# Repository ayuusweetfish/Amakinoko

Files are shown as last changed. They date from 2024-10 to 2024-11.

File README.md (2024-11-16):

# 天气蘑菇 · アマキノコ · Amakinoko

一个蘑菇外形的彩灯装置，流动的颜色依天气变化。光效亦可通过 USB 连接电脑定制。

[**汇报展示与视频**](https://ayuusweetfish.github.io/Amakinoko/)  
[**Rev. 2 资料**](https://github.com/ayuusweetfish/Amakinoko/releases/tag/rev-2)

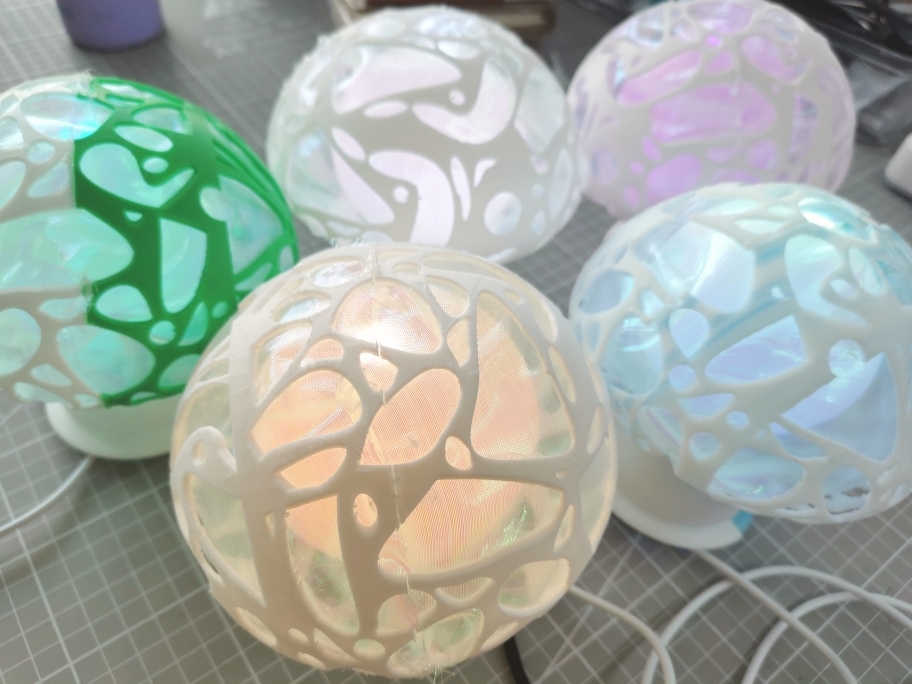
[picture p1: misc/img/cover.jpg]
封面图，蘑菇外形的色彩各异的灯


## 食谱

材料
- 3D 打印外壳元件
- 炫彩纱布（？）
- WS2812/WS2812B 灯带（5050 灯珠；每米 96 灯，取 24 灯）
- 2.54 mm 排针
- 2.54 mm 跳线（杜邦线），双端孔头
- 组装电路板（PCBA）
- 胶水，如 UHU 胶
- （可选）热熔胶
- （可选）镀银纱线

步骤
1. 将纱布用胶水粘贴在两片外壳上；
2. 将 3 pin 排针焊接在灯带首端；
3. 将灯带打结成球状，尽可能使每一个朝向都有小灯；
4. 将灯带上的排针插入杜邦线，连接至电路板；
5. 将灯带与杜邦线固定在内胆内侧（可用胶水或热熔胶），保持灯带悬空在中央位置；
6. （可选）若有镀银纱线，可将其随意粘贴在外壳内壁，另一端穿过电路板上的触摸传感孔，打结、粘贴固定；
7. 将外壳与内胆粘贴固定；
8. 连接 USB 电源即可。

注：3D 打印与 PCBA 的组装未列入。PCBA 组装可参考 KiCad 工程文件；完成后通过 DAP 调试器向 STM32 微控制器写入固件，再通过蘑菇配置工具写入灯光程序。

## 定制灯光

通过 USB 数据线将装置连接至计算机，运行配置工具软件（发布页面提供 Windows 与 macOS 版本下载）。连接后即可看到实时读数、灯光颜色与光效程序。

光效程序运行在 [Mumu 虚拟机](./misc/mumu)中，目前以 Mumu 汇编语言撰写。Mumu 是一个结构简单的虚拟计算模型，其上的程序能访问 2 KiB 的内存空间。

## 目录组织
- **hw/**: 印刷电路板工程文件
- **fw/**: STM32 微控制器固件源程序
- **mech/**: 外壳 3D 模型
- **cfg/**: PC 配置工具软件源程序

部分文件可以通过以下软件打开（版本号作为参考）：
- 外壳：3D One
- 电路板：KiCad (7.0.10)
- 固件：Arm GNU Toolchain (GCC 10.3.1), STM32CubeG0 (1.5.0), PlatformIO (6.1.16)

## 许可

本仓库内的所有内容按照 CERN-OHL-S（CERN 开放硬件许可证第 2 版，强互惠条件）分发。完整原文参见 **COPYING.txt** 或[在线访问](https://ohwr.org/cern_ohl_s_v2.txt)。

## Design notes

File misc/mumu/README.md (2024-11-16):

# 微木 · Mumu

Mumu 是一个结构简单的虚拟机（抽象的计算模型），可以在资源有限的平台上创造相对灵活的计算环境。

## Mumu 计算模型

- Harvard 架构，随机存储（RAM）与只读存储（ROM）分离，每个存储单元均为 32 位
- 程序从 ROM 地址 0 处开始执行，每条指令占一个存储单元
- 256 个“通用寄存器” %0 \~ %255，直接映射到随机存储单元 0 \~ 255
- “堆栈指针寄存器” SP 为随机存储单元 M-1，其中 M 为随机存储单元总数

## Mumu 汇编语言

单个大写字母均表示寄存器（均指通用寄存器，不包括 SP，下同）。

参考：[Fibonacci 数列](./fib.mumu)、[天气蘑菇彩虹光效](./lights/3.mumu)。

### 算术
```
<op>  <A> <B> <C>     # A := B (op) C
<op>  <A> <B> <Imm8>  # A := B (op) Imm8
<op>  <A> <Imm16>     # A := A (op) Imm16
<op>  <A> <Imm16>     # A := A (op) (Imm16 << 16)
```
其中 `<op>` 为 `mov`/`add`/`sub`/`mul`/`and`/`or`/`xor`/`bic`/`lsr`/`asr`/`lsl` 之一。

### 访存
```
ld    <A> <B> <C>  # A := RAM[B + C]
st    <A> <B> <C>  # RAM[B + C] := A
ldc   <A> <B> <C>  # A := ROM[B + C]
ldcr  <A> <B> <C>  # A := ROM[PC + B + C]
```
另外，访存指令中所有的 `<C>` 也可以为 8 位立即值。

### 控制流
```
br<cond>  <A> <B> <Imm8>      # PC := PC + Imm8
br<cond>  <A> <Imm8B> <Imm8C> # PC := PC + Imm8C
br<cond>  <A> <B> <C>         # PC := PC + C
ba<cond>  <A> <B> <C>         # PC := C
baf       <Imm24>             # PC := Imm24
```
其中 `<cond>` 为 `al`/`eq`/`ne`/`gt`/`lt`/`ge`/`le`/`sgt`/`slt`/`sge`/`sle` 之一。

### 堆栈与子过程
```
push  <A> <Imm8>    # SP := SP - Imm8; RAM[SP..=SP+Imm8-1] = A..=A+Imm8-1
pop   <A> <Imm8>    # A..=A+Imm8-1 = RAM[SP..=SP+Imm8-1]; SP := SP + Imm8
call  <Imm24>       # push PC+1; baf Imm24
ret                 # pop PC
```

### 系统呼叫
```
sc  <Imm24>
```

## Mulin

希望以后能提供更加易于上手的语言。暂时还没有开始。

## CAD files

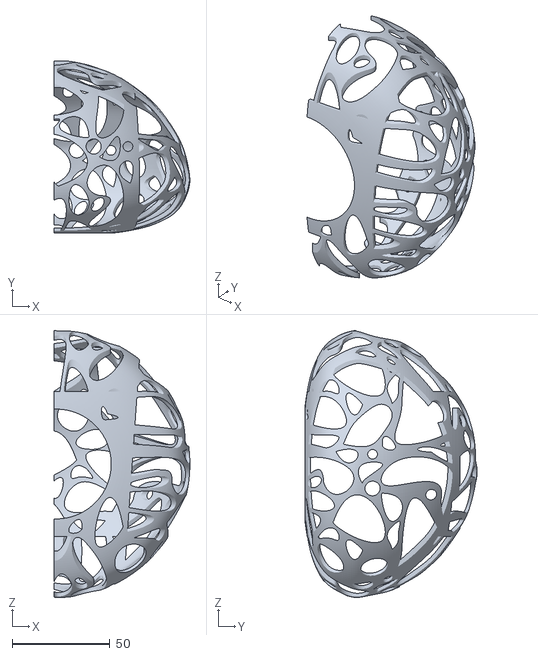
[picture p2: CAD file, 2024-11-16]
mech/rev2/蘑菇2.0（头2）.stl
69.5 x 88.3 x 136.7

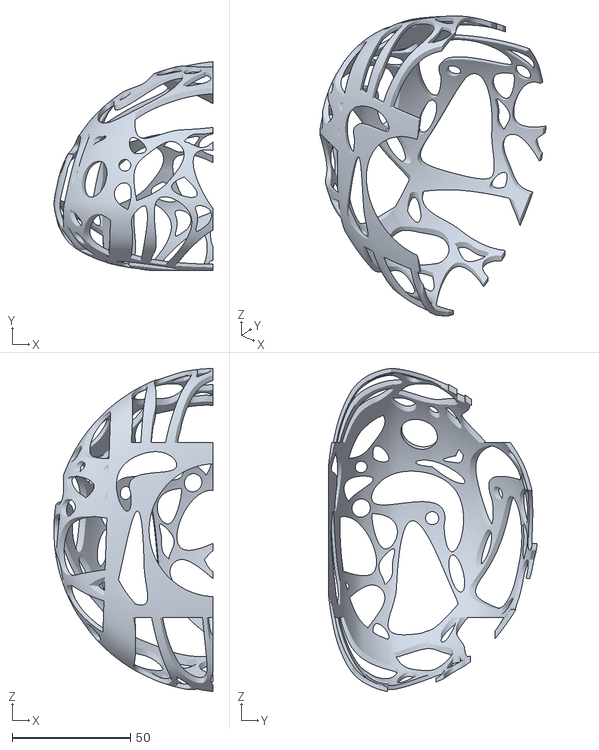
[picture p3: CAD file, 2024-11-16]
mech/rev2/蘑菇2.0(头1).stl
67.1 x 88.1 x 136.5

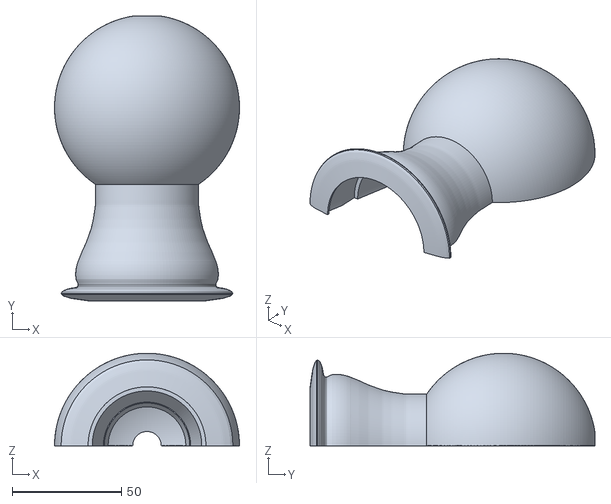
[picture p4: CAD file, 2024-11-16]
mech/rev2/蘑菇2.0（身）.stl
84.8 x 130.5 x 42.4

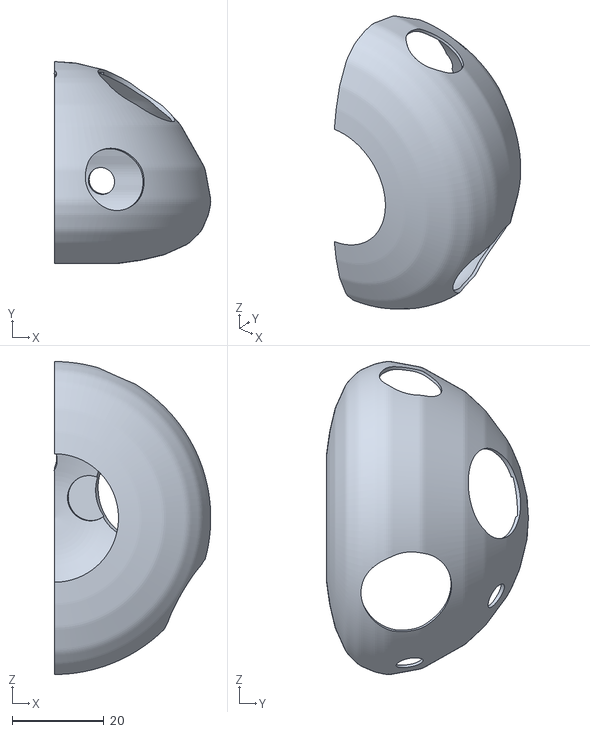
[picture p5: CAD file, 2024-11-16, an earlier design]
mech/rev1/小蘑菇头2.stl
34.2 x 44.1 x 68.4

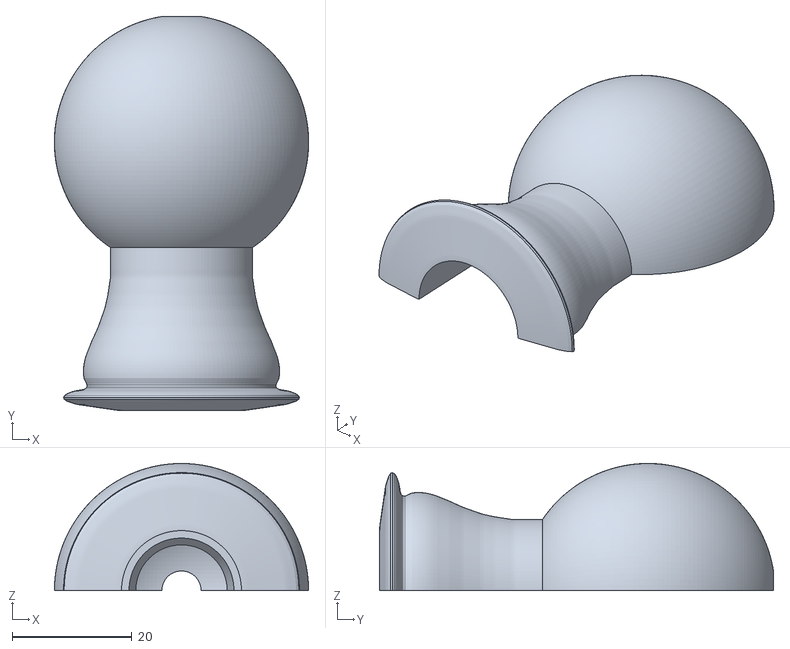
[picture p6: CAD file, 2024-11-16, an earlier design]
mech/rev1/小蘑菇柄1.stl
42.4 x 65.7 x 21.2

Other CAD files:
mech/rev1/小蘑菇头1.stl
mech/rev1/小蘑菇柄2.stl

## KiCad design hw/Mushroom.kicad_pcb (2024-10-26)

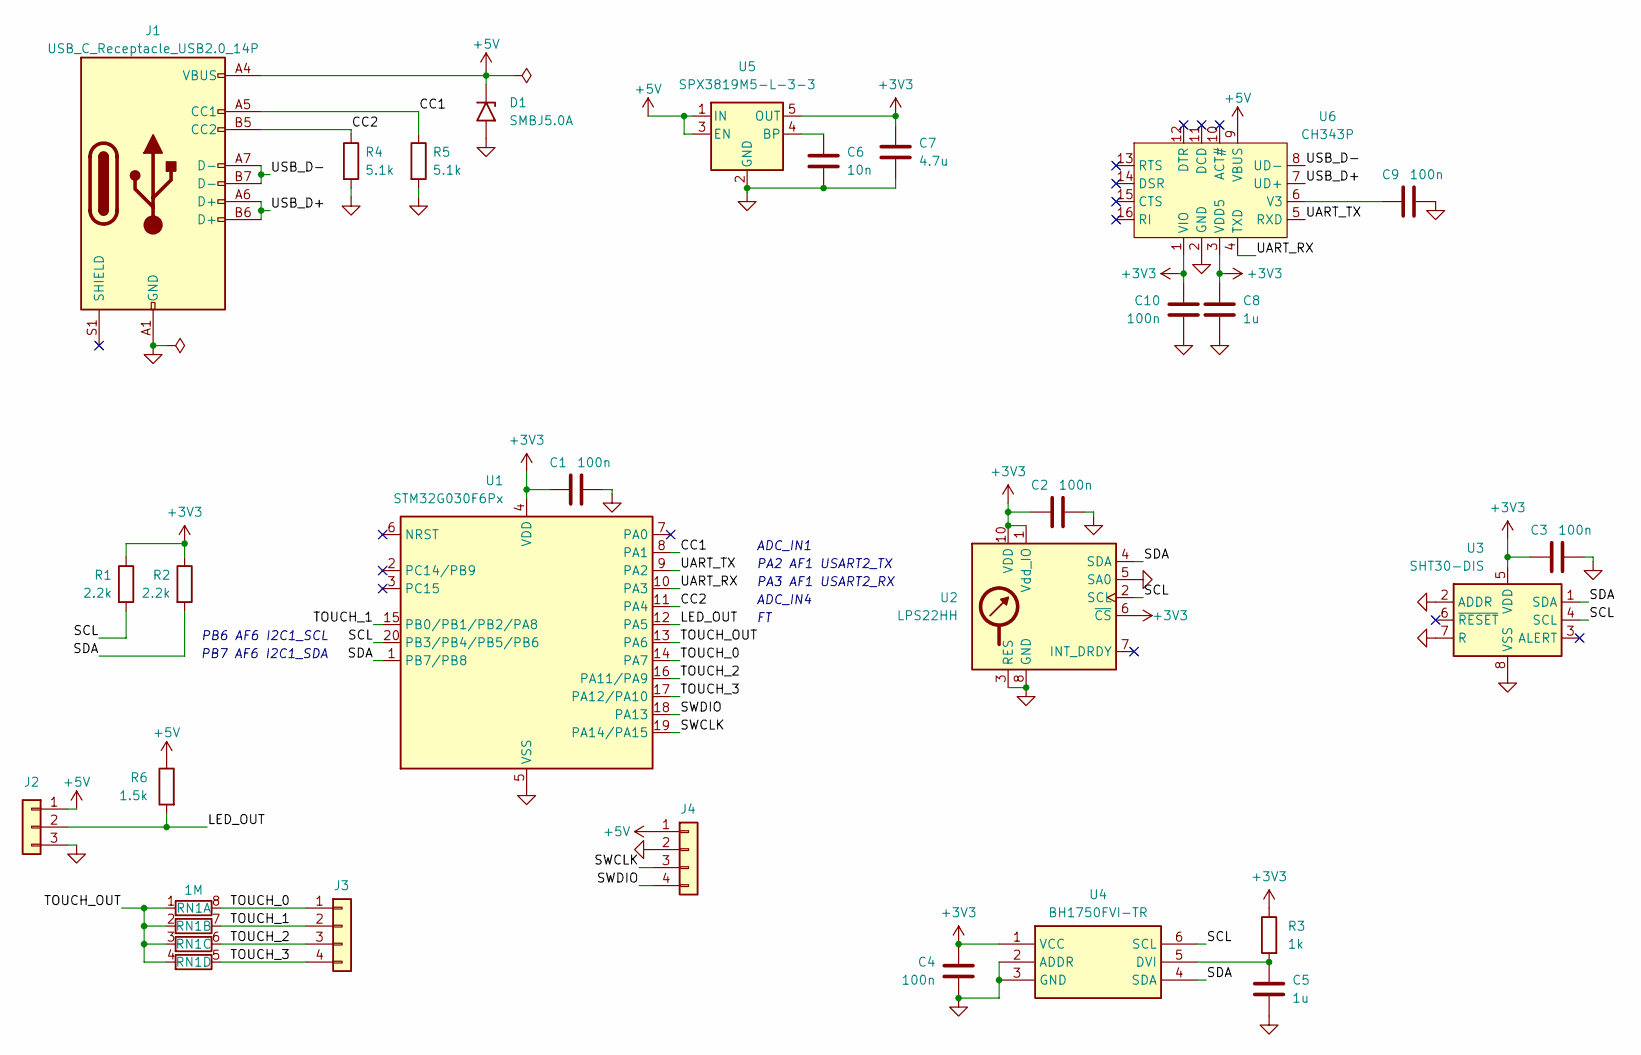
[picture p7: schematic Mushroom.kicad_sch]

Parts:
C1, C2, C3, C4, C9, C10: 100n; C_0402_1005Metric
C5, C8: 1u; C_0402_1005Metric
C6: 10n; C_0402_1005Metric
C7: 4.7u; C_0402_1005Metric
D1: SMBJ5.0A; D_SMB
J1: USB_C_Receptacle_USB2.0_14P; USB_C_Receptacle_HRO_TYPE-C-31-M-12
J2: Conn_01x03; PinHeader_1x03_P2.54mm_Vertical
J3: Conn_01x04; Arc_Pins_04
J4: Conn_01x04; TestPoints_1x04_P2.0
R1, R2: 2.2k; R_0402_1005Metric
R3: 1k; R_0402_1005Metric
R4, R5: 5.1k; R_0402_1005Metric
R6: 1.5k; R_0402_1005Metric
RN1: 1M; R_Array_Convex_4x0402
U1: STM32G030F6Px; TSSOP-20_4.4x6.5mm_P0.65mm
U2: LPS22HH; ST_HLGA-10_2x2mm_P0.5mm_LayoutBorder3x2y
U3: SHT30-DIS; Sensirion_DFN-8-1EP_2.5x2.5mm_P0.5mm_EP1.1x1.7mm
U4: BH1750FVI-TR; WSOF6; Manufacturer_Part_Number BH1750FVI-TR; Mouser Part Number 755-BH1750FVI-TR
U5: SPX3819M5-L-3-3; SOT-23-5
U6: CH343P; QFN-16-1EP_3x3mm_P0.5mm_EP1.9x1.9mm

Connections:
+3V3: C1.1, C2.1, C3.1, C4.1, C7.1, C8.1, C10.1, R1.1, R2.1, R3.1, U1.4 (VDD), U2.1 (Vdd_IO), U2.6 (~CS), U2.10 (VDD), U3.5 (VDD), U4.1 (VCC), U5.5 (OUT), U6.1 (VIO), U6.3 (VDD5)
+5V: D1.1 (A1), J1.A4 (VBUS), J1.A9 (VBUS), J1.B4 (VBUS), J1.B9 (VBUS), J2.1, J4.1, R6.1, U5.1 (IN), U5.3 (EN), U6.9 (VBUS)
/CC1: J1.A5 (CC1), R5.1, U1.8 (PA1)
/CC2: J1.B5 (CC2), R4.1, U1.11 (PA4)
/LED_OUT: J2.2, R6.2, U1.12 (PA5)
/SCL: R1.2, U1.20 (PB3/PB4/PB5/PB6), U2.2 (SCL), U3.4 (SCL), U4.6 (SCL)
/SDA: R2.2, U1.1 (PB7/PB8), U2.4 (SDA), U3.1 (SDA), U4.4 (SDA)
/SWCLK: J4.3, U1.19 (PA14/PA15)
/SWDIO: J4.4, U1.18 (PA13)
/TOUCH_0: J3.1, RN1.8 (R1.2), U1.14 (PA7)
/TOUCH_1: J3.2, RN1.7 (R2.2), U1.15 (PB0/PB1/PB2/PA8)
/TOUCH_2: J3.3, RN1.6 (R3.2), U1.16 (PA11/PA9)
/TOUCH_3: J3.4, RN1.5 (R4.2), U1.17 (PA12/PA10)
/TOUCH_OUT: RN1.1 (R1.1), RN1.2 (R2.1), RN1.3 (R3.1), RN1.4 (R4.1), U1.13 (PA6)
/UART_RX: U1.10 (PA3), U6.4 (TXD)
/UART_TX: U1.9 (PA2), U6.5 (RXD)
/USB_D+: J1.A6 (D+), J1.B6 (D+), U6.7 (UD+)
/USB_D-: J1.A7 (D-), J1.B7 (D-), U6.8 (UD-)
GND: C1.2, C2.2, C3.2, C4.2, C5.2, C6.2, C7.2, C8.2, C9.2, C10.2, D1.2 (A2), J1.A1 (GND), J1.A12 (GND), J1.B1 (GND), J1.B12 (GND), J2.3, J4.2, R4.2, R5.2, U1.5 (VSS), U2.3 (RES), U2.5 (SA0), U2.8 (GND), U2.9 (GND), U3.2 (ADDR), U3.7 (R), U3.8 (VSS), U3.9 (VSS), U4.2 (ADDR), U4.3 (GND), U5.2 (GND), U6.2 (GND), U6.17 (GND)
unnamed: C5.1, R3.2, U4.5 (DVI)
unnamed: C6.1, U5.4 (BP)
unnamed: C9.1, U6.6 (V3)

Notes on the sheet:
PB6 AF6 I2C1_SCL
PA2 AF1 USART2_TX
ADC_IN1
PA3 AF1 USART2_RX
ADC_IN4
PB7 AF6 I2C1_SDA

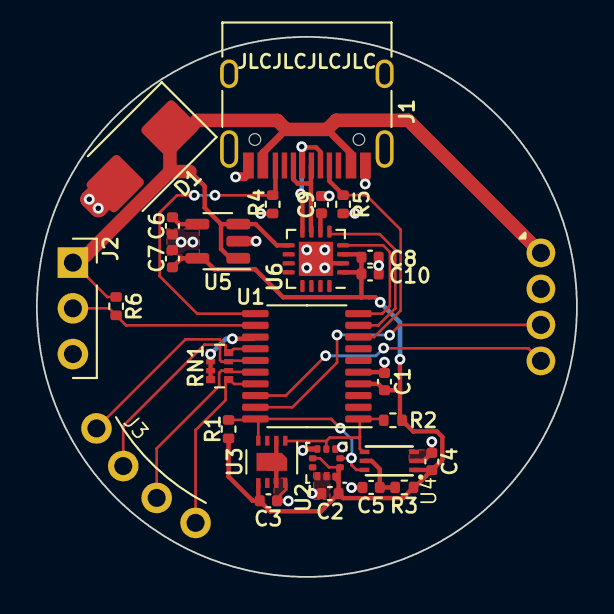
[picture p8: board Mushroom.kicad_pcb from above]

Board: 2 copper layers, 30.0 x 30.0 mm, 28 parts (0 on the bottom side), 22 nets.

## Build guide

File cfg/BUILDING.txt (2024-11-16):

# main

make

make DEBUG=1

make WIN=1

# libui

cd libui
meson setup --buildtype=release --default-library=static build
ninja -C build

# MinGW build needs to suppress a warning due to windows/areadraw.cpp:81
meson setup --buildtype=release --default-library=static --cross-file=<(echo "[binaries]
c = 'x86_64-w64-mingw32-gcc'
cpp = 'x86_64-w64-mingw32-g++'
ar = 'x86_64-w64-mingw32-ar'
windres = 'x86_64-w64-mingw32-windres'
strip = 'x86_64-w64-mingw32-strip'
exe_wrapper = 'wine64'

[host_machine]
system = 'windows'
cpu_family = 'x86_64'
cpu = 'x86_64'
endian = 'little'
") -Dcpp_args='-Wno-narrowing' build_win

# libserialport

# Note: Due to `kIOMasterPortDefault` -> `kIOMainPortDefault` deprecation and renaming,
# the macOS version might crash without a reason (bad access).
# In this case, manually enable `#define` at libserialport_internal.h:97 and rebuild.
diff --git a/libserialport_internal.h b/libserialport_internal.h
index 57346d6..03e4af3 100644
--- a/libserialport_internal.h
+++ b/libserialport_internal.h
@@ -93,7 +93,7 @@
 #include <IOKit/serial/ioss.h>
 #include <sys/syslimits.h>
 #include <mach/mach_time.h>
-#if MAC_OS_X_VERSION_MAX_ALLOWED < 120000 /* Before macOS 12 */
+#if 1 /* Before macOS 12 */
 #define kIOMainPortDefault kIOMasterPortDefault
 #endif
 #endif

cd libserialport
./autogen.sh
./configure
make

cd libserialport_win
./autogen.sh
./configure --host=x86_64-w64-mingw32
make

# zlib

cd zlib
./configure && make

cd zlib_win
make PREFIX=x86_64-w64-mingw32- -fwin32/Makefile.gcc

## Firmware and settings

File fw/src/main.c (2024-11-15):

#include <stm32g0xx_hal.h>
#include <assert.h>
#include <math.h>
#include <stdarg.h>
#include <stdatomic.h>
#include <stdbool.h>
#include <stdint.h>
#include <stdio.h>
#include <string.h>

#define MUMU_ROM_SIZE 1024
#define MUMU_RAM_SIZE 512
static volatile bool mumu_run_timeout;
#define MUMU_TIMEOUT_CONDITION mumu_run_timeout
#include "../../misc/mumu/mumu.h"

#define REV 2

extern uint32_t _sidata, _sdata, _edata;
#define FLASH_START_ADDR    0x08000000
#define FW_END_ADDR         ((uint32_t)&_sidata + ((uint32_t)&_edata - (uint32_t)&_sdata))
#define STORAGE_START_ADDR  ((FW_END_ADDR + FLASH_PAGE_SIZE - 1) & ~(FLASH_PAGE_SIZE - 1))
#define STORAGE_SIZE        4096
#define FLASH_END_ADDR      (FLASH_START_ADDR + (32 * 1024))
_Static_assert(STORAGE_SIZE % FLASH_PAGE_SIZE == 0);

#define STORAGE_ROM_LEN_OFFS  (STORAGE_SIZE - 4)
#define STORAGE_SRC_LEN_OFFS  (STORAGE_SIZE - 2)
#define STORAGE_ROM_OFFS      (0)
#define STORAGE_SRC_OFFS      (MUMU_ROM_SIZE)
#define STORAGE_ROM_LEN       ((uint16_t *)(STORAGE_START_ADDR + STORAGE_ROM_LEN_OFFS))
#define STORAGE_SRC_LEN       ((uint16_t *)(STORAGE_START_ADDR + STORAGE_SRC_LEN_OFFS))
#define STORAGE_ROM_START     ((void *)(STORAGE_START_ADDR + STORAGE_ROM_OFFS))
#define STORAGE_SRC_START     ((void *)(STORAGE_START_ADDR + STORAGE_SRC_OFFS))
#define STORAGE_ROM_MAX_LEN   (MUMU_ROM_SIZE)
#define STORAGE_SRC_MAX_LEN   (STORAGE_SIZE - 4 - STORAGE_SRC_OFFS)

// #define RELEASE
#ifndef RELEASE
#define _release_inline
static uint8_t swv_buf[256];
static size_t swv_buf_ptr = 0;
__attribute__ ((noinline, used))
void swv_trap_line()
{
  *(volatile char *)swv_buf;
}
static inline void swv_putchar(uint8_t c)
{
  // ITM_SendChar(c);
  if (c == '\n') {
    swv_buf[swv_buf_ptr >= sizeof swv_buf ?
      (sizeof swv_buf - 1) : swv_buf_ptr] = '\0';
    swv_trap_line();
    swv_buf_ptr = 0;
  } else if (++swv_buf_ptr <= sizeof swv_buf) {
    swv_buf[swv_buf_ptr - 1] = c;
  }
}
__attribute__ ((format(printf, 1, 2)))
static void swv_printf(const char *restrict fmt, ...)
{
  char s[256];
  va_list args;
  va_start(args, fmt);
  int r = vsnprintf(s, sizeof s, fmt, args);
  for (int i = 0; i < r && i < sizeof s - 1; i++) swv_putchar(s[i]);
  if (r >= sizeof s) {
    for (int i = 0; i < 3; i++) swv_putchar('.');
    swv_putchar('\n');
  }
}
#else
#define _release_inline inline
#define swv_printf(...)
#endif

__attribute__ ((section(".RamFunc")))
static inline void spin_delay(uint32_t cycles)
{
  __asm__ volatile (
    "   cmp %[cycles], #5\n"
    "   ble 2f\n"
    "   sub %[cycles], #5\n"
    "   lsr %[cycles], #2\n"
    "1: sub %[cycles], #1\n"
    "   nop\n"
    "   bne 1b\n"   // 2 cycles if taken
    "2: \n"
    : [cycles] "+l" (cycles)
    : // No output
    : "cc"
  );
}
__attribute__ ((section(".RamFunc")))
static inline void delay_us(uint32_t us)
{
  spin_delay(us * 64);
}

static UART_HandleTypeDef uart2;

#define N_LIGHTS 24
static mumu_vm_t m = { 0 };
static uint32_t *const lights = m.m + 256;
static uint8_t timeout_cooldown = 0;
static void output_lights();

static uint8_t rx_byte;

static void queue_tx_flush();
static void tx_readings_if_connected();

static _Atomic bool irqs_happened;
static _Atomic bool flash_rewritten;

__attribute__ ((section(".RamFunc")))
static void storage_write(uint32_t offs, const uint8_t data[256])
{
  // Silently break if offset not of a multiple of fast-write burst length (32 double-words)
  if (offs % (32 * 8) != 0) return;
  // Silently break if data is not properly aligned
  if ((uint32_t)&data[0] % 8 != 0) return;

  HAL_FLASH_Unlock();

  // Fast programming only works with the last erased page
  // https://community.st.com/t5/stm32-mcus-embedded-software/stm32g0-and-flash-typeprogram-fast-fail/m-p/122457/highlight/true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
  // https://community.st.com/t5/stm32-mcus-products/stm32g0-flash-program-fast-on-non-last-erased-page/td-p/72284
  static uint32_t last_written_page = 0;
  if (offs == 0 || offs / FLASH_PAGE_SIZE != last_written_page) {
    last_written_page = offs / FLASH_PAGE_SIZE;
    uint32_t page_err;
    HAL_FLASHEx_Erase(&(FLASH_EraseInitTypeDef){
      .TypeErase = FLASH_TYPEERASE_PAGES,
      .Banks = FLASH_BANK_1,
      .Page = (STORAGE_START_ADDR - FLASH_START_ADDR + offs) / FLASH_PAGE_SIZE,
      .NbPages = 1,
    }, &page_err);
  }

  __disable_irq();
  HAL_FLASH_Program(FLASH_TYPEPROGRAM_FAST, STORAGE_START_ADDR + offs, (uint32_t)&data[0]);
  __enable_irq();
  HAL_FLASH_Lock();
}

// Pull a set of pins to a given level and set them as input
static inline void pull_electrodes_port(GPIO_TypeDef *port, uint32_t pins, bool level)
{
  GPIO_InitTypeDef gpio_init = (GPIO_InitTypeDef){
    .Mode = GPIO_MODE_OUTPUT_PP,
    .Pin = pins,
    .Pull = GPIO_NOPULL,
    .Speed = GPIO_SPEED_FREQ_VERY_HIGH,
  };
  HAL_GPIO_Init(port, &gpio_init);
  HAL_GPIO_WritePin(port, pins, level);
  gpio_init.Mode = GPIO_MODE_INPUT;
  HAL_GPIO_Init(port, &gpio_init);
}

#define N_ELECTRODES 4

#if REV == 1
  #define BTN_OUT_PORT  GPIOC
  #define BTN_OUT_PIN   GPIO_PIN_15
  #define TOUCH_PINS_A  ((1 << 0) | (1 << 1) | (1 << 2) | (1 << 3))
  #define TOUCH_MASK_   1 << 0, 1 << 1, 1 << 2, 1 << 3,
#elif REV == 2
  #define BTN_OUT_PORT  GPIOA
  #define BTN_OUT_PIN   GPIO_PIN_6
  #define TOUCH_PINS_A  ((1 << 7) | (1 << 8) | (1 << 11) | (1 << 12))
  #define TOUCH_MASK_   1 << 7, 1 << 8, 1 << 11, 1 << 12,
#endif

static const uint16_t TOUCH_MASK[N_ELECTRODES] = { TOUCH_MASK_ };

static inline void pull_electrodes(bool level)
{
  pull_electrodes_port(GPIOA, TOUCH_PINS_A, level);
}

#pragma GCC push_options
#pragma GCC optimize("O3")
static inline void cap_sense(uint16_t cap_sum[N_ELECTRODES])
{
  struct record_t {
    uint16_t t;
    uint16_t v;
  } record[16];

  static const uint16_t FULL_MASK =
    TOUCH_MASK[0] | TOUCH_MASK[1] | TOUCH_MASK[2] | TOUCH_MASK[3];

  uint16_t cap[4] = { 0 };
  for (int i = 0; i < N_ELECTRODES; i++) cap_sum[i] = 0;

  inline void toggle(const bool level) {
    pull_electrodes(1 - level); // Pull to the opposite level before reading
    int n_records;

    // Instead of depending on timers, we simply retry if interrupts happen midway
    do {
      n_records = 0;
      uint16_t last_v = (level == 1 ? ~FULL_MASK : FULL_MASK);
      record[n_records] = (struct record_t){.t = (uint16_t)-1, .v = last_v};

      HAL_SuspendTick();
      irqs_happened = false;
      HAL_GPIO_WritePin(BTN_OUT_PORT, BTN_OUT_PIN, level);
      for (int i = 0; i < 100; i++) {
        uint32_t combined_v = GPIOA->IDR;
        uint16_t cur_v = (level == 1 ? (combined_v | last_v) : (combined_v & last_v));
        if (last_v != cur_v) n_records++;
        record[n_records] = (struct record_t){.t = i, .v = cur_v};
        last_v = cur_v;
      }
      HAL_ResumeTick();
    } while (irqs_happened);

    for (int j = 0; j < N_ELECTRODES; j++) cap[j] = 0xffff;
    for (int i = 1; i <= n_records; i++) {
      uint16_t t = record[i - 1].t + 1;
      uint16_t diff = record[i - 1].v ^ record[i].v;
      for (int j = 0; j < N_ELECTRODES; j++)
        if (diff & TOUCH_MASK[j]) cap[j] = t;
    }
    for (int j = 0; j < N_ELECTRODES; j++)
      if (cap_sum[j] == 0xffff || cap[j] == 0xffff) cap_sum[j] = 0xffff;
      else cap_sum[j] += cap[j];
  }
  for (int its = 0; its < 5; its++) {
    toggle(1);
    toggle(0);
  }

  // Maintain a base value for each of the buttons

  // The base value increases by 1 every 16 iterations (~ 0.5 second)
  static const uint32_t BASE_MULT = 16;
  static uint32_t base[N_ELECTRODES] = { UINT32_MAX };
  if (base[0] == UINT32_MAX) {
    for (int j = 0; j < N_ELECTRODES; j++) base[j] = cap_sum[j] * BASE_MULT;
  } else {
    for (int j = 0; j < N_ELECTRODES; j++) {
      base[j] += 1;
      uint32_t lower = cap_sum[j] * BASE_MULT;
      if (base[j] > lower)
        base[j] = lower + (base[j] - lower) * 3 / 4;
    }
  }
  for (int j = 0; j < N_ELECTRODES; j++) {
    uint32_t base_scaled = base[j] / BASE_MULT;
    cap_sum[j] = (cap_sum[j] > base_scaled ? cap_sum[j] - base_scaled : 0);
  }
}
#pragma GCC pop_options

static inline void adc_start()
{
  while (!(ADC1->CR & ADC_CR_ADEN)) {
    ADC1->CR = (ADC1->CR & ~(ADC_CR_ADCAL | ADC_CR_ADSTP | ADC_CR_ADSTART | ADC_CR_ADDIS)) | ADC_CR_ADEN;
  }
}
static inline uint32_t adc_poll_value()
{
  ADC1->ISR = (ADC_ISR_EOC | ADC_ISR_EOS | ADC_ISR_OVR);  // All bits of ADC_ISR are r/cw1
  ADC1->CR = ADC_CR_ADSTART;  // All bits of ADC_CR are r/s
  while (!(ADC1->ISR & ADC_FLAG_EOC)) { }
  return ADC1->DR;
}
static inline void adc_stop()
{
  ADC1->CR = (ADC1->CR & ~(ADC_CR_ADCAL | ADC_CR_ADSTP | ADC_CR_ADSTART | ADC_CR_ADDIS)) | ADC_CR_ADSTP;
  while (ADC1->CR & ADC_CR_ADSTART) { }
  ADC1->CR = (ADC1->CR & ~(ADC_CR_ADCAL | ADC_CR_ADSTP | ADC_CR_ADSTART | ADC_CR_ADDIS)) | ADC_CR_ADDIS;
  while (ADC1->CR & ADC_CR_ADEN) { }
}

#if REV == 1
  #define LED_OUT_PORT  GPIOB
  #define LED_OUT_PIN   (1 << 9)
#elif REV == 2
  #define LED_OUT_PORT  GPIOA
  #define LED_OUT_PIN   (1 << 5)
  #define CC1_ADC_CHANNEL 1
  #define CC2_ADC_CHANNEL 4
#endif

struct sensors_readings {
  uint32_t t;   // (LPS22HH, SHT30) Temperature (0.01 degC)
  uint32_t p;   // (LPS22HH) Pressure (Pa)
  uint32_t h;   // (SHT30) Humidity (0.01 %RH)
  uint32_t i;   // (BH1750FVI) Illuminance (lx)
  uint8_t c[4]; // Capacitive sensing
};
static struct sensors_readings last_readings;
static uint8_t last_readings_valid = 0; // Bitmask for the 3 sensors
static uint32_t frame_n = 0;

static inline uint16_t offs_clamp_16(uint32_t x, uint32_t offs)
{
  if (x < offs) return 0;
  x -= offs;
  return (x > 0xffff ? 0xffff : x);
}

#define TX_READINGS_LEN (14 + 1 + N_LIGHTS * 3)
static void fill_tx_readings(uint8_t buf[TX_READINGS_LEN])
{
  buf[ 0] = (frame_n >> 8) & 0xff;
  buf[ 1] = (frame_n >> 0) & 0xff;
  buf[ 2] = (last_readings.t >> 8) & 0xff;
  buf[ 3] = (last_readings.t >> 0) & 0xff;
  buf[ 4] = (last_readings.p >> 8) & 0xff;
  buf[ 5] = (last_readings.p >> 0) & 0xff;
  buf[ 6] = (last_readings.h >> 8) & 0xff;
  buf[ 7] = (last_readings.h >> 0) & 0xff;
  buf[ 8] = (last_readings.i >> 8) & 0xff;
  buf[ 9] = (last_readings.i >> 0) & 0xff;
  buf[10] = last_readings.c[0];
  buf[11] = last_readings.c[1];
  buf[12] = last_readings.c[2];
  buf[13] = last_readings.c[3];

  buf[14] = last_readings_valid | (timeout_cooldown > 0 ? 0x10 : 0x00);

  for (int i = 0; i < N_LIGHTS; i++) {
    buf[14 + 1 + i * 3 + 0] = (lights[i] >> 16) & 0xff;
    buf[14 + 1 + i * 3 + 1] = (lights[i] >>  8) & 0xff;
    buf[14 + 1 + i * 3 + 2] = (lights[i] >>  0) & 0xff;
  }
}

int main()
{
  HAL_Init();

  // ======== GPIO ========
  __HAL_RCC_GPIOA_CLK_ENABLE();
  __HAL_RCC_GPIOB_CLK_ENABLE();
  __HAL_RCC_GPIOC_CLK_ENABLE();
  GPIO_InitTypeDef gpio_init;

  // SWD (PA13, PA14)
  gpio_init.Pin = GPIO_PIN_13 | GPIO_PIN_14;
  gpio_init.Mode = GPIO_MODE_AF_PP; // Pass over control to AF peripheral
  gpio_init.Alternate = GPIO_AF0_SWJ;
  gpio_init.Pull = GPIO_PULLUP;
  gpio_init.Speed = GPIO_SPEED_FREQ_HIGH;
  HAL_GPIO_Init(GPIOA, &gpio_init);

  // ======== Clocks ========
  // Voltage scaling mostly affects clocks (HSE, PLL) and flash latency
  // Refer to RM0454 Rev. 5
  // - Ch. 4.1.4, "Dynamic voltage scaling management"
  // - Ch. 3.3.4, "FLASH read access latency"
  HAL_PWREx_ControlVoltageScaling(PWR_REGULATOR_VOLTAGE_SCALE1);

  RCC_OscInitTypeDef osc_init = { 0 };
  osc_init.OscillatorType = RCC_OSCILLATORTYPE_HSI;
  osc_init.HSIState = RCC_HSI_ON;
  osc_init.HSICalibrationValue = RCC_HSICALIBRATION_DEFAULT;
  osc_init.PLL.PLLState = RCC_PLL_ON;
  osc_init.PLL.PLLSource = RCC_PLLSOURCE_HSI;
  osc_init.PLL.PLLM = RCC_PLLM_DIV1;  // VCO input 16 MHz (2.66 ~ 16 MHz)
  osc_init.PLL.PLLN = 8;              // VCO output 128 MHz (64 ~ 344 MHz)
  osc_init.PLL.PLLP = RCC_PLLP_DIV2;  // PLLPCLK 64 MHz
  osc_init.PLL.PLLR = RCC_PLLR_DIV2;  // PLLRCLK 64 MHz
  HAL_RCC_OscConfig(&osc_init);

  RCC_ClkInitTypeDef clk_init = { 0 };
  clk_init.ClockType =
    RCC_CLOCKTYPE_SYSCLK |
    RCC_CLOCKTYPE_HCLK |
    RCC_CLOCKTYPE_PCLK1;
  clk_init.SYSCLKSource = RCC_SYSCLKSOURCE_PLLCLK;  // 64 MHz
  clk_init.AHBCLKDivider = RCC_SYSCLK_DIV1;         // 64 MHz
  clk_init.APB1CLKDivider = RCC_HCLK_DIV1;          // 64 MHz
  HAL_RCC_ClockConfig(&clk_init, FLASH_LATENCY_2);

#if REV == 2
  // ======== UART ========
  HAL_GPIO_Init(GPIOA, &(GPIO_InitTypeDef){
    .Pin = GPIO_PIN_2 | GPIO_PIN_3,
    .Mode = GPIO_MODE_AF_PP,
    .Alternate = GPIO_AF1_USART2,
    .Speed = GPIO_SPEED_FREQ_VERY_HIGH,
  });
  __HAL_RCC_USART2_CLK_ENABLE();
  uart2 = (UART_HandleTypeDef){
    .Instance = USART2,
    .Init = (UART_InitTypeDef){
      .BaudRate = 921600,
      .WordLength = UART_WORDLENGTH_8B,
      .StopBits = UART_STOPBITS_1,
      .Parity = UART_PARITY_NONE,
      .Mode = UART_MODE_TX_RX,
      .HwFlowCtl = UART_HWCONTROL_NONE,
      .OverSampling = UART_OVERSAMPLING_16,
    },
  };
  HAL_UART_Init(&uart2);
  HAL_NVIC_SetPriority(USART2_IRQn, 1, 0);
  HAL_NVIC_EnableIRQ(USART2_IRQn);
  HAL_UART_Receive_IT(&uart2, &rx_byte, 1);
#endif

  // ======== Capacitive touch sensing ========
  // BTN_OUT
  gpio_init = (GPIO_InitTypeDef){
    .Pin = BTN_OUT_PIN,
    .Mode = GPIO_MODE_OUTPUT_PP,
    .Pull = GPIO_NOPULL,
    .Speed = GPIO_SPEED_FREQ_VERY_HIGH,
  };
  HAL_GPIO_Init(BTN_OUT_PORT, &gpio_init);
  HAL_GPIO_WritePin(BTN_OUT_PORT, BTN_OUT_PIN, 0);

  // For the electrodes, refer to `pull_electrodes()`

  uint32_t cc_mV_max = 0;
#if defined(CC1_ADC_CHANNEL) && defined(CC2_ADC_CHANNEL)
{
  // ======== ADC for CC pins ========
  __HAL_RCC_ADC_CLK_ENABLE();
  ADC_HandleTypeDef adc1 = {
    .Instance = ADC1,
    .Init = {
      .ClockPrescaler = ADC_CLOCK_ASYNC_DIV1,
      .Resolution = ADC_RESOLUTION_12B,
      .DataAlign = ADC_DATAALIGN_RIGHT,
      .ScanConvMode = ADC_SCAN_SEQ_FIXED,
      .EOCSelection = ADC_EOC_SINGLE_CONV,
      .LowPowerAutoWait = DISABLE,
      .LowPowerAutoPowerOff = ENABLE,
      .ContinuousConvMode = DISABLE,
      .NbrOfConversion = 1,
      .DiscontinuousConvMode = DISABLE,
      .ExternalTrigConv = ADC_SOFTWARE_START,
      .TriggerFrequencyMode = ADC_TRIGGER_FREQ_LOW,
    },
  };
  HAL_ADC_Init(&adc1);
  HAL_ADCEx_Calibration_Start(&adc1);
  adc_stop();

  ADC1->SMPR = 0b110; // 79.5 cycles

  // Internal reference
  ADC1_COMMON->CCR |= ADC_CCR_VREFEN;
  ADC1->CHSELR = (1 << 13);
  adc_start();
  uint32_t adc_vrefint = adc_poll_value();
  adc_stop();
  ADC1_COMMON->CCR &= ~ADC_CCR_VREFEN;
  // CC1
  ADC1->CHSELR = (1 << CC1_ADC_CHANNEL);
  adc_start();
  uint32_t adc_cc1 = adc_poll_value();
  adc_stop();
  // CC2
  ADC1->CHSELR = (1 << CC2_ADC_CHANNEL);
  adc_start();
  uint32_t adc_cc2 = adc_poll_value();
  adc_stop();

  uint32_t vrefint_cal = *VREFINT_CAL_ADDR;
  uint32_t cc1_mV = (uint32_t)(3000ULL * adc_cc1 * vrefint_cal / (4095 * adc_vrefint));
  uint32_t cc2_mV = (uint32_t)(3000ULL * adc_cc2 * vrefint_cal / (4095 * adc_vrefint));
  cc_mV_max = (cc1_mV > cc2_mV ? cc1_mV : cc2_mV);
  swv_printf("CC voltage %lu | %lu %lu %lu\n", cc_mV_max, adc_cc1, adc_cc2, adc_vrefint);

  __HAL_RCC_ADC_CLK_DISABLE();
}
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

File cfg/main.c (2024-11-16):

#include "libui/ui.h"
#include "libserialport/libserialport.h"
#include "zlib.h"
#include <math.h>
#include <pthread.h>
#include <stdbool.h>
#define _GNU_SOURCE
#include <stdio.h>
#include <stdlib.h>
#include <string.h>
#include <unistd.h> // usleep

#include "crc32.h"

#include "mumu_as.h"

static bool dump_data = false;

static uiWindow *w;

static int on_should_quit(void *_unused)
{
  return 1;
}

static char global_err_msg[256];
#define ensure_or_act(_cond, _act, ...) do { \
  if (!(_cond)) { \
    snprintf(global_err_msg, sizeof global_err_msg, __VA_ARGS__); \
    _act; \
  } \
} while (0)
#define ensure_or_abort(_cond, ...) ensure_or_act(_cond, error_and_abort(), __VA_ARGS__)
#define ensure_or_ret(_val, _cond, ...) ensure_or_act(_cond, return _val, __VA_ARGS__)

static inline void clear_status_bar();
static inline void status_bar(const char *s);

static void error_and_abort()
{
  uiMsgBox(w, "", global_err_msg);
  exit(1);
}
static void error_and_continue()
{
  uiMsgBox(w, "", global_err_msg);
  clear_status_bar();
  if (0) {
    char *s;
    asprintf(&s, "× %s", global_err_msg);
    status_bar(s);
    free(s);
  }
}

static uiButton *btn_show_program;
static uiBox *box_program, *box_fill;
// `box_fill` is a workaround for libui's stretch bug
// where (at least on macOS) a single hidden stretchy element
// results in the first (non-stretchy) element being stretched

static uiLabel
  *lbl_readings_t, *lbl_readings_p, *lbl_readings_h, *lbl_readings_i, *lbl_readings_c;
static uiArea
  *area_readings_t, *area_readings_p, *area_readings_h, *area_readings_i, *area_readings_c;

static uiArea *area_lights;

static uiMultilineEntry *text_source;
static uiButton *btn_check, *btn_upload;
static uiLabel *lbl_status_bar;

static int expanded_height;
static inline void fold_program()
{
  uiButtonSetText(btn_show_program, "▷ 程序");
  uiControlHide(uiControl(box_program));
  uiControlShow(uiControl(box_fill));

  int width, height;
  uiWindowContentSize(w, &width, &height);
  expanded_height = height;
  uiWindowSetContentSize(w, width, 0);
}
static inline void expand_program()
{
  uiButtonSetText(btn_show_program, "▽ 程序");
  uiControlShow(uiControl(box_program));
  uiControlHide(uiControl(box_fill));

  int width, height;
  uiWindowContentSize(w, &width, &height);
  uiWindowSetContentSize(w, width, expanded_height);
}
static inline void btn_show_program_clicked(uiButton *btn, void *_unused)
{
  if (uiControlVisible(uiControl(box_program))) fold_program();
  else expand_program();
}

static inline void clear_status_bar()
{
  uiLabelSetText(lbl_status_bar, "");
}
static inline void status_bar(const char *s)
{
  uiLabelSetText(lbl_status_bar, s);
}

struct readings_t {
  double t, p, h;
  int i;
  uint8_t c[4];
} last_readings;

static bool readings_is_valid = false;
static bool readings_integrity_notified;  // Reset at connection establishment

static uint8_t lights[24][3] = {{ 0 }};

static void clear_readings_disp()
{
  uiLabelSetText(lbl_readings_t, "温度：— ˚C");
  uiLabelSetText(lbl_readings_p, "气压：— hPa");
  uiLabelSetText(lbl_readings_h, "湿度：— % RH");
  uiLabelSetText(lbl_readings_i, "光照：— lx");
  uiLabelSetText(lbl_readings_c, "触摸：—");
  for (int i = 0; i < 4; i++) last_readings.c[i] = 0;
  readings_is_valid = false;
  uiAreaQueueRedrawAll(area_readings_t);
  uiAreaQueueRedrawAll(area_readings_p);
  uiAreaQueueRedrawAll(area_readings_h);
  uiAreaQueueRedrawAll(area_readings_i);
  uiAreaQueueRedrawAll(area_readings_c);
  uiAreaQueueRedrawAll(area_lights);
  uiControlDisable(uiControl(btn_upload));
}

#define TX_READINGS_LEN 14
static void parse_readings(const uint8_t buf[TX_READINGS_LEN])
{
  uint16_t T = ((uint16_t)buf[ 0] << 8) | buf[ 1];
  uint16_t t = ((uint16_t)buf[ 2] << 8) | buf[ 3];
  uint16_t p = ((uint16_t)buf[ 4] << 8) | buf[ 5];
  uint16_t h = ((uint16_t)buf[ 6] << 8) | buf[ 7];
  uint16_t i = ((uint16_t)buf[ 8] << 8) | buf[ 9];

  last_readings.t = (double)t / 100;
  last_readings.p = (double)((uint32_t)p + 65536) / 100;
  last_readings.h = (double)h / 100;
  last_readings.i = (int)i;
  memcpy(last_readings.c, buf + 10, 4);
  readings_is_valid = true;

  char s[64];
  snprintf(s, sizeof s, "温度：%.1f ˚C", last_readings.t);
  uiLabelSetText(lbl_readings_t, s);
  snprintf(s, sizeof s, "气压：%.1f hPa", last_readings.p);
  uiLabelSetText(lbl_readings_p, s);
  snprintf(s, sizeof s, "湿度：%.1f%% RH", last_readings.h);
  uiLabelSetText(lbl_readings_h, s);
  snprintf(s, sizeof s, "光照：%d lx", last_readings.i);
  uiLabelSetText(lbl_readings_i, s);
  int c_max = 0;
  for (int i = 0; i < 4; i++) if (c_max < last_readings.c[i]) c_max = last_readings.c[i];
  snprintf(s, sizeof s, "触摸：%d%%", (c_max * 100 + 127) / 255);
  uiLabelSetText(lbl_readings_c, s);
  uiAreaQueueRedrawAll(area_readings_t);
  uiAreaQueueRedrawAll(area_readings_p);
  uiAreaQueueRedrawAll(area_readings_h);
  uiAreaQueueRedrawAll(area_readings_i);
  uiAreaQueueRedrawAll(area_readings_c);
  uiAreaQueueRedrawAll(area_lights);
}

// 0x56, <readings> (TX_READINGS_LEN), <status>, <lights> (RGB8, N*3)
#define IS_PACKET_READINGS(_len, _buf) \
  ((_len) >= TX_READINGS_LEN + 2 && (_buf)[0] == 0x56)

// buf[0] is length; buf[1..=length] is payload
static void parse_continuous_rx(void *_buf)
{
  uint8_t *buf = _buf;
  uint8_t len = buf[0];
  buf++;
  if (IS_PACKET_READINGS(len, buf)) {
    parse_readings((const uint8_t *)(buf + 1));

    uint8_t readings_valid_mask = buf[TX_READINGS_LEN + 1] & 0x0f;
    bool timeout = (buf[TX_READINGS_LEN + 1] & 0x10) != 0;
    char s[64];
    s[0] = '\0';
    if (timeout) {
      strcpy(s, "* 程序超时");
    }
    if (readings_valid_mask != 0x07 && (s[0] != '\0' || !readings_integrity_notified)) {
      readings_integrity_notified = true;
      int len = strlen(s);
      snprintf(s + len, sizeof s - len, "%s传感器数据不完整 (%u)",
        len == 0 ? "* " : " / ", (unsigned)readings_valid_mask);
    }
    if (s[0] != '\0') status_bar(s);

    int n_lights = (len - (TX_READINGS_LEN + 2)) / 3;
    if (n_lights > 24) n_lights = 24;
    memcpy(lights, (const uint8_t *)(buf + (TX_READINGS_LEN + 2)), n_lights * 3);
  }
  free(_buf);
}
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

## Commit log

2024-10-16 🚧 Initial commit; empty hardware project
    [Mushroom.kicad_pcb, Mushroom.kicad_sch]
2024-10-18 Add testrun firmware (board is Curtain Rev. 1)
2024-10-21 Finish schematic
    [Mushroom.kicad_sch]
2024-10-21 🚧 Preliminary layout & routing
    [Mushroom.kicad_pcb, Mushroom.kicad_sch]
2024-10-21 Finish board design
    [Mushroom.kicad_pcb, Mushroom.kicad_sch]
2024-10-21 Revise and finalise board design
    [Mushroom.kicad_pcb]
2024-10-21 🎉 Submit for fab (Rev. 1)
    [Mushroom.kicad_pcb, Mushroom.kicad_sch]
2024-10-21 Change board setup to white / 1 mm
    [Mushroom.kicad_pcb]
2024-10-25 🎉 Initial firmware
2024-10-25 I2C SCL line stuck low?
    [main.c]
2024-10-25 Toggle LED data output pin
2024-10-25 Restore I2C check
    Previous issue: BH1750FVI was soldered in the wrong direction
    [main.c]
2024-10-25 ✨ Flowing lights!
2024-10-25 Fix I2C timing setting
    [main.c]
2024-10-26 Fix I2C bus stuck issue (output should be open-drain)
    [main.c]
2024-10-26 Revise board schematic
    [Mushroom.kicad_sch]
2024-10-26 Preliminary layout & routing
    [Mushroom.kicad_pcb, Mushroom.kicad_sch]
2024-10-26 🎉 Finalise design; submit for fab (Rev. 2)
    [Mushroom.kicad_pcb]
2024-10-26 Fix TX/RX lines; re-submit for fab (Rev. 2)
    Previous order was cancelled (Y52, Y53)
    [Mushroom.kicad_pcb, Mushroom.kicad_sch]
2024-10-27 Clean-up of sensor-reading subroutine
2024-10-27 Incorporate sensor readings into the display loop
2024-10-27 Release WS2812 signal line when idle to avoid continuous draining current
    [main.c]
2024-10-28 Implement capacitive sensing
2024-10-28 Incorporate capacitance sensing into main loop
2024-10-31 🎉 A new VM??
2024-10-31 Optimise a bit 😈
2024-11-02 mumu: 🚧 Assembler
2024-11-02 mumu: 🚧 Parse mnemonics
2024-11-02 mumu: 🚧 Assemble most instructions
    TODO: memory, forward label patching
2024-11-02 mumu: 🎉 Assemble the Fibonacci program
2024-11-04 fw: Working UART
2024-11-05 cfg: 🚧 Non-working refresh... T T
2024-11-06 fw: Sense CC pin voltage
2024-11-06 fw: Fix format-print warnings
    [main.c]
2024-11-06 cfg: Check device signature
2024-11-06 fw, cfg: Increase baud rate to 921k6; misc. bug fixes
    [main.c]
2024-11-07 cfg: Parse and display readings! 🎉
2024-11-08 cfg: Replace with connect/disconnect button
    [main.c]
2024-11-09 fw, cfg: Fix handshake failure by correctly waiting for state reset
    [main.c]
2024-11-10 fw, cfg: Transmit program binary and source from device
2024-11-10 fw, cfg: Load source text into GUI; add placeholder check/upload buttons
2024-11-11 fw: Eliminate IRQ disabling during touch sensing
    Cannot use DMA as we need to check each byte for its time of arrival. Or maybe use a flag and clear it often...? How to deal with ongoing transmissions at time of check in this case?
2024-11-11 fw: Eliminate IRQ blocks during LED write (🚧 untested)
2024-11-11 fw, cfg: Correctly uploading data! 🎉
    [main.c]
2024-11-11 fw: Fix error when uploading more than one row (256 bytes)
    [main.c]
2024-11-11 cfg: 🚧 GUI redesign
    [main.c]
2024-11-11 cfg: 🚧 GUI redesign (2/n)
    [main.c]
2024-11-11 cfg: 🚧 GUI redesign (3/n)
    [main.c]
2024-11-11 cfg: GUI redesign (done, hopefully)
    [main.c]
2024-11-13 mumu-as, cfg: Refactor assembler into separate header/source pair
2024-11-13 cfg: Assemble source
2024-11-13 cfg: 🎉 Upload assembled binary and source!
2024-11-13 fw: 🎉 Run user programs for real!
2024-11-13 cfg: Fix buffer overflow bug
    Also checked against leaks, none found ^ ^
    [main.c]
2024-11-14 cfg: Switch to monospaced typeface for code
2024-11-14 fw: Display pre-made pattern in case of timeout
2024-11-14 lights: Add new program 🚧
2024-11-14 lights: Separate R, G, B rather than compressed 🚧
2024-11-14 fw: Fix WS281x timing glitches
    [main.c]
2024-11-14 fw: Fix incorrect stack pointer after upload
    Generates spurious timeouts
    [main.c]
2024-11-14 fw: Reset entire Mumu RAM (thus program state) after a timeout
    [main.c]
2024-11-15 cfg: Fix Windows build
    [main.c]
2024-11-15 cfg: Flush serial buffer before sending handshake message
    In case a message from an unterminated previous connexion arrives. This might reduce failure by a bit, but anyway, the best solution is to connect ACT#...
    [main.c]
2024-11-15 lights: Flowing lights 🚧 (too fast!)
2024-11-15 lights: Flowing rainbows again, this time with Mumu! 🌈✨
2024-11-15 fw: Properly reset VM if flash write occurs midway
    [main.c]
2024-11-16 cfg: Do not fail on source decompression error
    [main.c]
2024-11-16 mech: Add casing
    [小蘑菇头1.stl, 小蘑菇头2.stl, 小蘑菇柄1.stl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]
2024-11-16 cfg: Building on Windows 🎉
2024-11-16 docs: A lot of documentation. Pinned for release 🎉
